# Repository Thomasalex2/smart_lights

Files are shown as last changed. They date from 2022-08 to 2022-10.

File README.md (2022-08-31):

# Smart Lights with WS2812 and ESP Rainmaker

A WS2812 Smart light written for ESP32 on Rainmaker for a complete DIY alternative solution to all well known market brands.

I've always loved how the [Nanoleaf Lights](https://nanoleaf.me/) looked as a decor item/accent lights in a room but it has always been a bit too expensive for me to ever get one.

And as electronics and software engineer, I figured it would be quite easy create my own version for like about the 10th of the cost and even more features (like motion detection)

## Demo
https://user-images.githubusercontent.com/24490575/187764227-740f462d-60de-43a5-915d-b5e42f166fa6.mp4

Note: The shadow parts are not as visbile with nakes eye as compared to the footage recorded on the camera (we can thank our eye's superiror dynamic range for that)

## Hardware Used
- ESP32
- WS2812 64 bit RGB Matrix
- RCWL-0516 Microwave Doppler motion detector
- 5V 5A adaptor (you may need to change this depending on the number of LEDs you plan to use)
- Wire connectors
- [3D printable hexagons (credits to DeDane1970)](https://www.thingiverse.com/thing:4831115/files)
- Good ol' 3M double sided tape

## Features
- WiFi connected System
- Fully controllable through ESP Rainmaker App
- Supports control with Google Assistant and Alexa
- Customize the lights to any color with color wheel
- Cycle gradually through all colour
- Split cycle mode giving each tile individual colours
- React to motion
- Turn on lights to low brightness when motion is detected

## Planned features
- Add OPT3001 to detect ambient light
- More options for colour transitions
- LED grouping Features
- Disco Mode

## Known Issues
- The setup can get stuck if brightness/saturation controls are used in Split cycle mode

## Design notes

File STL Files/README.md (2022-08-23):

# Source & Credits
https://www.thingiverse.com/thing:4831115/files

by DeDane1970

# Printing Information

The following settings were used to print all my enclosures (pictures will be added soon)

- FDM 3D Printing
- 0.2mm Precision
- 10% infill
- PLA - White

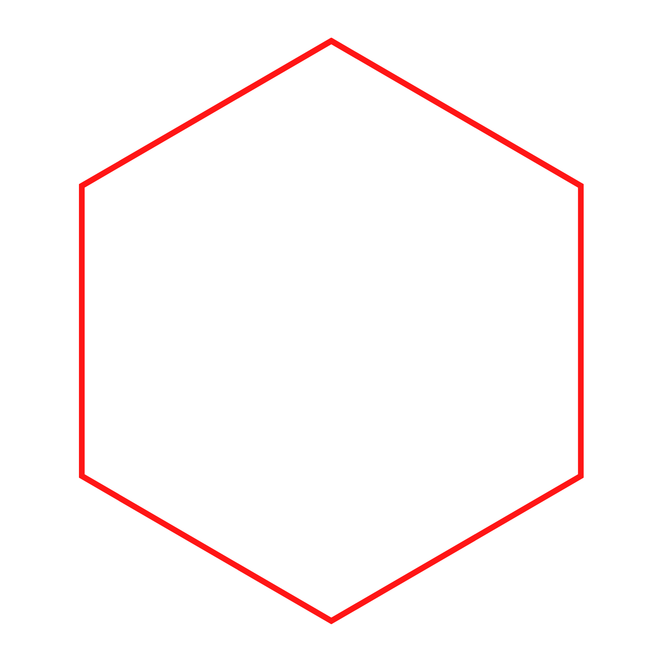
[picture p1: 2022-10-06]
Nanoleaf Hex.png

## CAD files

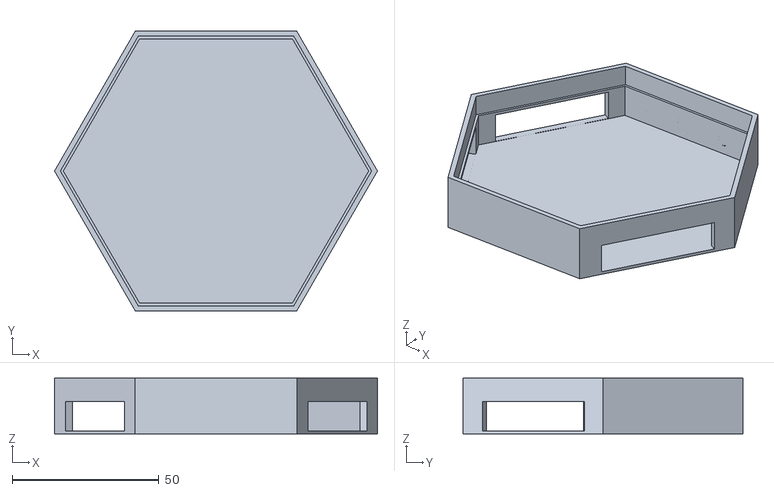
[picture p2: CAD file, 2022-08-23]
STL Files/Hex_4.stl
110.0 x 95.3 x 19.0

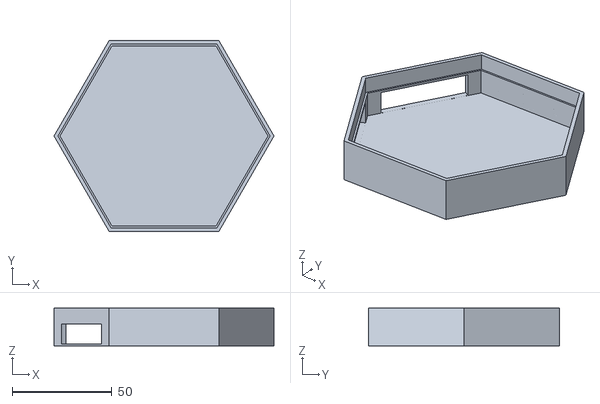
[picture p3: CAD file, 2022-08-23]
STL Files/Hex_3.stl
110.0 x 95.3 x 19.0

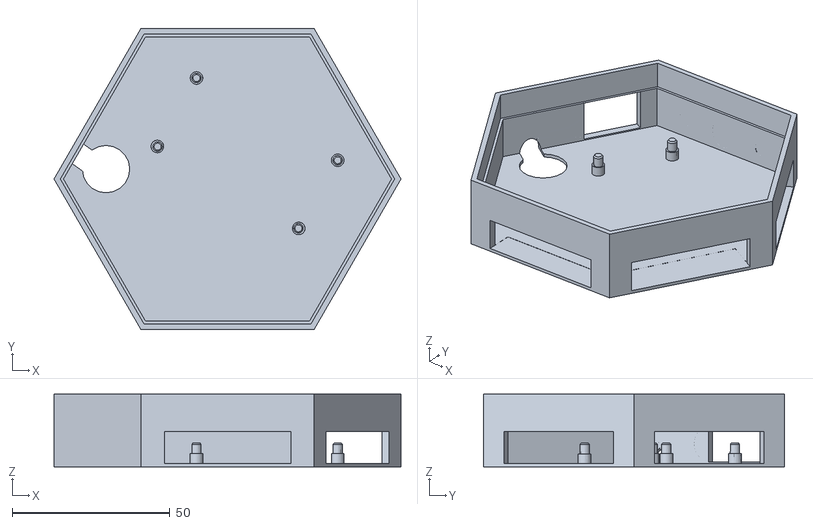
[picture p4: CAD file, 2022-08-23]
STL Files/Hexagon_power_box.stl
110.0 x 95.3 x 23.0

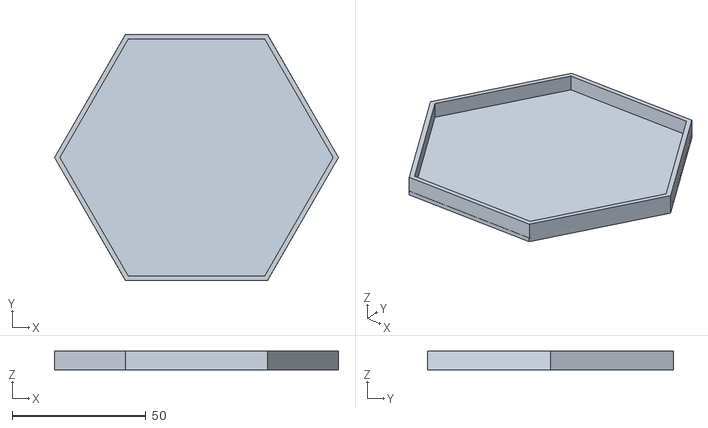
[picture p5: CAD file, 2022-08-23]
STL Files/Hexagon_Top.stl
106.0 x 92.0 x 7.00

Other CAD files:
STL Files/Hex_1.stl
STL Files/Hex_5.stl
STL Files/Hex_2.stl

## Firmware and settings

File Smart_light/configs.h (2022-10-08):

// Device Config
#define DEVICE_NAME "ESP_RAINMAKER"
#define RGB_LIGHTS "Nanoleaf"
#define PROV_PASSWORD "1234567"
#define GPIO_RESET 17

// Set Light Values
#define LED_PIN 26
#define LED_SET 64
#define DEFAULT_LIGHT true
#define DEFAULT_BRIGHTNESS 76
#define DEFAULT_SATURATION 255
#define DEFAULT_HUE 32
#define LED_VOLTS 5
#define LED_MAX_AMPS 1500

// LED CONFIG
#define LED_TYPE WS2812
#define NUM_LEDS 192
#define COLOR_ORDER GRB
#define COLOR_TRANSITION_DELAY 1
#define CYCLE_HUE_RATE 2
#define BLEND_RATE 5
#define SIGNAL_REPETITION_TIME 50000

// PRESET MODE CONFIGS
#define DEFAULT_COLOR_PRESET "Custom"
#define DEFAULT_COLOR_PALETTE "Forest"
#define DEFAULT_COLOR_CYCLE_TIME 20
#define DEFAULT_SPLIT_CYCLE_TIME 1000
#define DEFAULT_PALLETTE_CYCLE_TIME 10
#define NUMBER_OF_PALLETTES_DEFINED 6

// Motion Detectors Configuration
#define MOTION_PIN 27
#define DEFAULT_MOTION false
#define DEFAULT_NIGHT_MOTION false
#define DEFAULT_MOTION_AWARENESS_PERIOD 4000
#define COLOR_SHIFT 41
#define NIGHT_MOTION_BRIGHTNESS 100
#define NIGHT_MOTION_TIMEOUT 10000

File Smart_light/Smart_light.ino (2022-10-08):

#include <FastLED.h>
#include "RMaker.h"
#include "WiFi.h"
#include "WiFiProv.h"
#include <wifi_provisioning/manager.h>
#include "configs.h"

// BLE Credentials
const char *service_name = "PROV_" DEVICE_NAME;
const char *pop = PROV_PASSWORD;

// GPIO
bool light_state = false;
bool wifi_connected = 0;

// LED CONFIG
CRGB leds[NUM_LEDS];

// INITIAL VALUES
uint8_t appliedHue = DEFAULT_HUE;
uint8_t appliedSat = DEFAULT_SATURATION;
uint8_t appliedVal = DEFAULT_BRIGHTNESS;
uint8_t brightnessBeforeTurnOff = DEFAULT_BRIGHTNESS;
bool motion_detection = DEFAULT_MOTION;
bool night_motion_detection = DEFAULT_NIGHT_MOTION;

// Initialization Variables
String color_preset = DEFAULT_COLOR_PRESET;
String color_palette = DEFAULT_COLOR_PALETTE;

// Timing Variables
unsigned long int detection_time = 0;
unsigned long int last_color_change_time = 0;
unsigned long int transitionStartTime;

// Color Palette Struct
CRGBPalette16 currentPalette = ForestColors_p;

// struct palettes
// {
//   char userInput[30];
//   CRGBPalette16 definedPalette;
// };
// palettes colorPalette[NUMBER_OF_PALLETTES_DEFINED];

// Flag Variables
bool motion_flag = false;
bool night_motion_flag = false;
bool night_light_state = false;

CHSV colorCurrent;
CHSV colorStart;
CHSV colorTarget;

//------------------------------------------- Declaring Devices -----------------------------------------------------//

// The framework provides some standard device types like switch, lightbulb, fan, temperature sensor.
static LightBulb ws2812(RGB_LIGHTS);

void sysProvEvent(arduino_event_t *sys_event)
{
  switch (sys_event->event_id) {
    case ARDUINO_EVENT_PROV_START:
    #if CONFIG_IDF_TARGET_ESP32
          Serial.printf("\nProvisioning Started with name \"%s\" and PoP \"%s\" on BLE\n", service_name, pop);
          printQR(service_name, pop, "ble");
    #else
          Serial.printf("\nProvisioning Started with name \"%s\" and PoP \"%s\" on SoftAP\n", service_name, pop);
          printQR(service_name, pop, "softap");
    #endif
      break;
    case ARDUINO_EVENT_WIFI_STA_CONNECTED:
      Serial.printf("\nConnected to Wi-Fi!\n");
      wifi_connected = 1;
      delay(500);
      break;
    case ARDUINO_EVENT_PROV_CRED_RECV: {
        Serial.println("\nReceived Wi-Fi credentials");
        Serial.print("\tSSID : ");
        Serial.println((const char *) sys_event->event_info.prov_cred_recv.ssid);
        Serial.print("\tPassword : ");
        Serial.println((char const *) sys_event->event_info.prov_cred_recv.password);
        break;
      }
    case ARDUINO_EVENT_PROV_INIT:
      wifi_prov_mgr_disable_auto_stop(10000);
      break;
    case ARDUINO_EVENT_PROV_CRED_SUCCESS:
      Serial.println("Stopping Provisioning!!!");
      wifi_prov_mgr_stop_provisioning();
      break;
  }
}

void write_callback(Device *device, Param *param, const param_val_t val, void *priv_data, write_ctx_t *ctx)
{
  const char *device_name = device->getDeviceName();
  const char *param_name = param->getParamName();

  if (strcmp(device_name, RGB_LIGHTS) == 0)
  {
    if (strcmp(param_name, "Power") == 0)
    {
      Serial.printf("Received value = %s for %s - %s\n", val.val.b ? "true" : "false", device_name, param_name);
      light_state = val.val.b;
      if (light_state)
      {
        transitionHSVColor(appliedHue, appliedSat, brightnessBeforeTurnOff);
        Serial.println("Turning on " DEVICE_NAME);
      } 
      else 
      {
        color_preset = "Custom";
        brightnessBeforeTurnOff = appliedVal;
        transitionHSVColor(appliedHue, appliedSat, 0);
        Serial.println("Turning off " DEVICE_NAME);
      }
    }
    else if (strcmp(param_name, "Brightness") == 0)
    {
      Serial.printf("Received value = %d for %s - %s\n", val.val.i, device_name, param_name);
      uint8_t newVal = map(val.val.i, 0, 100, 0, 255);
      transitionHSVColor(appliedHue, appliedSat, newVal);
    }
    else if (strcmp(param_name, "Hue") == 0)
    {
      Serial.printf("Received value = %d for %s - %s\n", val.val.i, device_name, param_name);
      color_preset = "Custom";
      uint8_t newHue = map(val.val.i, 0, 360, 0, 255);
      transitionHSVColor(newHue, appliedSat, appliedVal);
    }
    else if (strcmp(param_name, "Saturation") == 0)
    {
      Serial.printf("Received value = %d for %s - %s\n", val.val.i, device_name, param_name);
      color_preset = "Custom";
      uint8_t newSat = map(val.val.i, 0, 100, 0, 255);
      transitionHSVColor(appliedHue, newSat, appliedVal);
    }
    else if (strcmp(param_name, "Colour Presets") == 0)
    {
      color_preset = val.val.s;
      Serial.printf("\nReceived value = %s for %s - %s\n", val.val.s, device_name, param_name);
    }
    else if (strcmp(param_name, "Colour Palettes") == 0)
    {
      color_palette = val.val.s;
      Serial.printf("\nReceived value = %s for %s - %s\n", val.val.s, device_name, param_name);
      changeColorPalette(color_palette);
    }
    else if (strcmp(param_name, "Motion Awareness") == 0)
    {
      motion_detection = val.val.b;
      Serial.println(motion_detection == true ? "Turning on Motion Awareness" : "Turning off Motion Awareness");
    }
    else if (strcmp(param_name, "Night Motion Detection") == 0)
    {
      night_motion_detection = val.val.b;
      Serial.println(night_motion_detection == true ? "Turning on Night Motion Awareness" : "Turning off Night Motion Awareness");
    }
    param->updateAndReport(val);
  }
}

void rainmakerResetListener() 
{
  // Read GPIO0 (external button to reset device
  if (digitalRead(GPIO_RESET) == LOW)
  { // Push button pressed
    Serial.printf("Reset Button Pressed!\n");
    // Key debounce handling
    delay(100);
    int startTime = millis();
    while (digitalRead(GPIO_RESET) == LOW)
      delay(50);
    int endTime = millis();

    if ((endTime - startTime) > 10000)
    {
      // If key pressed for more than 10secs, reset all
      Serial.printf("Reset to factory.\n");
      wifi_connected = 0;
      RMakerFactoryReset(2);
    }
    else if ((endTime - startTime) > 3000)
    {
      Serial.printf("Reset Wi-Fi.\n");
      wifi_connected = 0;
      // If key pressed for more than 3secs, but less than 10, reset Wi-Fi
      RMakerWiFiReset(2);
    }
  }
}

void initWS2812()
{
  FastLED.addLeds<LED_TYPE, LED_PIN, COLOR_ORDER>(leds, NUM_LEDS);
  FastLED.setMaxPowerInVoltsAndMilliamps(LED_VOLTS, LED_MAX_AMPS);
  FastLED.clear();
  if (DEFAULT_LIGHT)
  {
    fill_solid(leds, NUM_LEDS, CHSV(appliedHue, appliedSat, appliedVal));
  }
  FastLED.show();
}

void changeHSVcolor(int hue, int sat, int val)
{
  fill_solid(leds, NUM_LEDS, CHSV(hue, sat, val));
  FastLED.delay(1);
  appliedHue = hue;
  appliedSat = sat;
  appliedVal = val;
  last_color_change_time = millis();
}

// Somehow this function is corrupting the entire memory system (i don't know why)
// void initializeColorPalettes()
// {
//   Serial.println("Configuring palettes");
//   strncpy(colorPalette[0].userInput, "Rainbow", 20);
//   colorPalette[0].definedPalette = RainbowColors_p;

//   strncpy(colorPalette[1].userInput, "Rainbow Stripe", 20);
//   // colorPalette[1].userInput = "Rainbow Stripe";
//   colorPalette[1].definedPalette = RainbowStripeColors_p;

//   strncpy(colorPalette[2].userInput, "Clouds", 20);
//   // colorPalette[2].userInput = "Clouds";
//   colorPalette[2].definedPalette = CloudColors_p;

//   strncpy(colorPalette[3].userInput, "Party", 20);
//   // colorPalette[3].userInput = "Party";
//   colorPalette[3].definedPalette = PartyColors_p;

//   strncpy(colorPalette[4].userInput, "Ocean", 20);
//   // colorPalette[4].userInput = "Ocean";
//   colorPalette[4].definedPalette = OceanColors_p;

//   strncpy(colorPalette[5].userInput, "Lava", 20);
//   // colorPalette[5].userInput = "Lava";
//   colorPalette[5].definedPalette = LavaColors_p;

//   strncpy(colorPalette[6].userInput, "Forest", 20);
//   // colorPalette[6].userInput = "Forest";
//   colorPalette[6].definedPalette = ForestColors_p;
//   Serial.println("Done Configuring palettes");
// }

void splitColourSelector()
{
  static int counter = 0;
  static bool skip_ahead = false;
  static uint8_t prevHue = 0;
  uint8_t newHue = skip_ahead ? prevHue + COLOR_SHIFT * NUM_LEDS/LED_SET : prevHue + COLOR_SHIFT;
  Serial.printf("Counter: %i \t Hue: %i\n", counter, newHue);
  for (int i = 0 + (LED_SET * counter); i < LED_SET * (counter + 1); i += 8)
  {
    for (int j = 0; j < 8; j++)
    {
      leds[i + j] = CHSV(newHue, 255, appliedVal);
    }
    FastLED.delay(cubicwave8(i * 4) / 8.0);
    }
  counter++;
  if (counter * LED_SET >= NUM_LEDS)
  {
    counter = 0;
    skip_ahead = true;
  }
  else 
  {
    skip_ahead = false;
  }
  prevHue = newHue;
  FastLED.show();
  last_color_change_time = millis();
}

void transitionHSVColor(int targetHue, int targetSat, int targetVal)
{
  uint8_t k = 0;
  transitionStartTime = millis();
  Serial.printf("Target HSV values: %d, %d, %d -> %d, %d, %d\n", appliedHue, appliedSat, appliedVal, targetHue, targetSat, targetVal);
  CHSV colorStart = CHSV(appliedHue, appliedSat, appliedVal);
  CHSV colorTarget = CHSV(targetHue, targetSat, targetVal);
  CHSV colorCurrent = colorStart;

  while (colorCurrent != colorTarget)
  {
    colorCurrent = blend(colorStart, colorTarget, k, SHORTEST_HUES);
    Serial.printf("Current values: %d, %d, %d\n", colorCurrent.h, colorCurrent.s, colorCurrent.v);
    changeHSVcolor(colorCurrent.h, colorCurrent.s, colorCurrent.v);
    FastLED.delay(10);
    k++;
  }
  Serial.printf("Applied HSV values: %d, %d, %d\n", colorCurrent.h, colorCurrent.s, colorCurrent.v);
  Serial.print("Elapsed transition time: ");
  Serial.println((millis() - transitionStartTime) / 1000.0);
  last_color_change_time = millis();
}

void changeColorPalette(String userSelectedPalette)
{
  // char selectedPalette[30];
  // userSelectedPalette.toCharArray(selectedPalette, userSelectedPalette.length() + 1);
  // for (int i = 0; i < NUMBER_OF_PALLETTES_DEFINED; i++)
  // {
  //   if (strcmp(colorPalette[i].userInput, selectedPalette))
  //   {
  //     currentPalette = colorPalette[i].definedPalette;
  //     Serial.printf("Selected Palette: %s\n", selectedPalette);
  //     break;
  //   }
  // }

  // Teh above code was an effort to reduce this dumb if-else ladder but the initializing function is ruining everything for some inexclipble reason

  if (userSelectedPalette == "Clouds")
  {
    currentPalette = CloudColors_p;
  }
  else if (userSelectedPalette == "Rainbow")
  {
    currentPalette = RainbowColors_p;
  }
  else if (userSelectedPalette == "Rainbow Stripe")
  {
    currentPalette = RainbowStripeColors_p;
  }
  else if (userSelectedPalette == "Party")
  {
    currentPalette = PartyColors_p;
  }
  else if (userSelectedPalette == "Ocean")
  {
    currentPalette = OceanColors_p;
  }
  else if (userSelectedPalette == "Lava")
  {
    currentPalette = LavaColors_p;
  }
  else if (userSelectedPalette == "Forest")
  {
    currentPalette = ForestColors_p;
  }
}

void FillLEDsFromPaletteColors(uint8_t colorIndex)
{
  for (int i = 0; i < NUM_LEDS; ++i)
  {
    leds[i] = ColorFromPalette(currentPalette, colorIndex, appliedVal, LINEARBLEND);
    colorIndex += 3;
  }
  FastLED.show();
  last_color_change_time = millis();
}

void checkColorPresets() 
{
  // Serial.println("Checking color Preset");
  if (color_preset == "Cycle")
  {
    EVERY_N_MILLISECONDS(DEFAULT_COLOR_CYCLE_TIME)
    {
      uint8_t newHue = appliedHue + 1;
      changeHSVcolor(newHue, appliedSat, appliedVal);
    }
  }
  else if (color_preset == "Split Cycle")
  {
    EVERY_N_MILLISECONDS(DEFAULT_SPLIT_CYCLE_TIME)
    {
      splitColourSelector();
    }
  }
  else if (color_preset == "Palette")
  {
    EVERY_N_MILLISECONDS(DEFAULT_PALLETTE_CYCLE_TIME)
    {
      static uint8_t startIndex = 0;
      startIndex = startIndex + 1;
      FillLEDsFromPaletteColors(startIndex);
    }
  }
}

void checkForMotion()
{
  if (digitalRead(MOTION_PIN))
  {
    if(!motion_flag)
    {
      Serial.println("Motion detected");
      uint8_t prevHue = appliedHue;
      uint8_t newHue = appliedHue + COLOR_SHIFT;
      Serial.printf("Changing Hue: %d -> %d\n", prevHue, newHue);
      transitionHSVColor(newHue, appliedSat, appliedVal);
      FastLED.delay(DEFAULT_MOTION_AWARENESS_PERIOD);
      transitionHSVColor(prevHue, appliedSat, appliedVal);
      motion_flag = true;
    }
  }
  else {
    motion_flag = false;
  }
}

void checkForNightMotion()
{
  if (digitalRead(MOTION_PIN) && !night_motion_flag && !light_state)
  {
    Serial.println("Night motion detected");
    transitionHSVColor(appliedHue, appliedSat, NIGHT_MOTION_BRIGHTNESS);
    night_motion_flag = true;
    night_light_state = true;
    detection_time = millis();
  }
  else
  {
    night_motion_flag = false;
    if (millis() - detection_time > NIGHT_MOTION_TIMEOUT && !light_state && night_light_state)
    {
      transitionHSVColor(appliedHue, appliedSat, 0);
      night_light_state = false;
    } 
  }
}

void setup()
{
  // Configure the input GPIOs
  pinMode(GPIO_RESET, INPUT_PULLUP);
  pinMode(MOTION_PIN, INPUT);

  Serial.begin(115200);
  initWS2812();
  // initializeColorPalettes();

  //------------------------------------------- Declaring Node -----------------------------------------------------//
  Node my_node;
  my_node = RMaker.initNode("Nanoleaf");

  static const char *colorPresetModes[] = {"Custom", "Cycle", "Split Cycle", "Palette"};
  Param colorPresets("Colour Presets", ESP_RMAKER_PARAM_MODE, value(DEFAULT_COLOR_PRESET), PROP_FLAG_READ | PROP_FLAG_WRITE);
  colorPresets.addValidStrList(colorPresetModes, 4);
  colorPresets.addUIType(ESP_RMAKER_UI_DROPDOWN);
  ws2812.addParam(colorPresets);

  static const char *colorPalettesMode[] = {"Clouds", "Rainbow", "Rainbow Stripe", "Party", "Ocean", "Lava", "Forest"};
  Param colorPalettes("Colour Palettes", ESP_RMAKER_PARAM_MODE, value(DEFAULT_COLOR_PALETTE), PROP_FLAG_READ | PROP_FLAG_WRITE);
  colorPalettes.addValidStrList(colorPalettesMode, 7);
  colorPalettes.addUIType(ESP_RMAKER_UI_DROPDOWN);
  ws2812.addParam(colorPalettes);

  Param hueParam("Hue", "esp.param.hue", value((int)map(DEFAULT_HUE, 0, 255, 0, 360)), PROP_FLAG_READ | PROP_FLAG_WRITE);
  hueParam.addBounds(value(0), value(360), value(1));
  hueParam.addUIType(ESP_RMAKER_UI_HUE_SLIDER);
  ws2812.addParam(hueParam);

  Param brightnessParam("Brightness", "esp.param.brightness", value((int)map(DEFAULT_BRIGHTNESS, 0, 255, 0, 100)), PROP_FLAG_READ | PROP_FLAG_WRITE);
  brightnessParam.addBounds(value(0), value(100), value(1));
  brightnessParam.addUIType(ESP_RMAKER_UI_SLIDER);
  ws2812.addParam(brightnessParam);

  Param saturationParam("Saturation", "esp.param.saturation", value((int)map(DEFAULT_SATURATION, 0, 255, 0, 100)), PROP_FLAG_READ | PROP_FLAG_WRITE);
  saturationParam.addBounds(value(0), value(100), value(1));
  saturationParam.addUIType(ESP_RMAKER_UI_SLIDER);
  ws2812.addParam(saturationParam);

  // Param motionParam("Motion Awareness", "esp.param.power", value((bool)DEFAULT_MOTION), PROP_FLAG_READ | PROP_FLAG_WRITE);
  // motionParam.addUIType(ESP_RMAKER_UI_TOGGLE);
  // ws2812.addParam(motionParam);

  // Param nightMotionParam("Night Motion Detection", "esp.param.power", value((bool)DEFAULT_MOTION), PROP_FLAG_READ | PROP_FLAG_WRITE);
  // nightMotionParam.addUIType(ESP_RMAKER_UI_TOGGLE);
  // ws2812.addParam(nightMotionParam);

  // Standard switch device
  ws2812.addCb(write_callback);

  //------------------------------------------- Adding Devices in Node -----------------------------------------------------//
  my_node.addDevice(ws2812);

  // This is optional
  RMaker.enableOTA(OTA_USING_PARAMS);
  RMaker.setTimeZone("Asia/Kolkata");
  RMaker.enableTZService();
  RMaker.enableSchedule();

  Serial.printf("\nStarting ESP-RainMaker\n");
  RMaker.start();

  WiFi.onEvent(sysProvEvent);

#if CONFIG_IDF_TARGET_ESP32
  WiFiProv.beginProvision(WIFI_PROV_SCHEME_BLE, WIFI_PROV_SCHEME_HANDLER_FREE_BTDM, WIFI_PROV_SECURITY_1, pop, service_name);
#else
  WiFiProv.beginProvision(WIFI_PROV_SCHEME_SOFTAP, WIFI_PROV_SCHEME_HANDLER_NONE, WIFI_PROV_SECURITY_1, pop, service_name);
#endif
}

void loop()
{
  if (color_preset != "Custom")
  {
    checkColorPresets();
  }
  if (millis() - last_color_change_time > SIGNAL_REPETITION_TIME)
  {
    Serial.println("Signal Repetition Process");
    changeHSVcolor(appliedHue, appliedSat, appliedVal);
    last_color_change_time = millis();
    Serial.printf("HEAP SIZE: %zu\n", ESP.getFreeHeap());
  }
  rainmakerResetListener();
}

// C:/Users/Thomas Alex/AppData/Local/Temp/arduino-sketch-C4E55FD361A2D9C60CC7B1DE58A423F6/

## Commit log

2022-07-19 Added Radar Sensor - Added motion awareness feat - Added night detection feature - Refactored code
2022-08-08 So much refactoring/bug fixes - Changes device name to preprocessor - Saves previous brightness values - Changes Rainbow to Cycle preset - Fixed colour cycle bugs - Added feature to repeat signal in 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
    [Smart_light.ino, configs.h]
2022-08-23 Changed LEDs number
2022-08-23 Added the 3D files
    [Hex_1.stl, Hex_2.stl, Hex_3.stl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]
2022-08-29 Added split color cycle - Some known bugs - Cant change any settings without coming out of SCC
    [Smart_light.ino, configs.h]
2022-08-31 - Added refinements - Changed reset GPIO to 17 - Restructured code
    [Smart_light.ino, configs.h]
2022-10-08 Stable version without crashes (most of the time)
    [Smart_light.ino, configs.h]
